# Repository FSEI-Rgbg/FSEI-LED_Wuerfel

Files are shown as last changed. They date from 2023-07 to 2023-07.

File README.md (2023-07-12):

# FSEI - LED Würfel - Lötübung

Dieses Projekt wurde als Lötübung ins Leben gerufen. Es handelt sich um eine kleine Platine mit 7 LEDs und einem Taster. Beim Drücken des Tasters wird eine Zahl zwischen 1 und 6 gewürfelt, wie bei einem echten Würfel auch.

## Wie sieht denn der Würfel eigentlich aus?
Bei einem solchen Projekt darf natürlich der FSEIgel nicht fehlen. Er hat selbstverständlich seinen ganz eigenen Platz auf der Platine bekommen.<p>
Wuerfel Version v1.0<p>
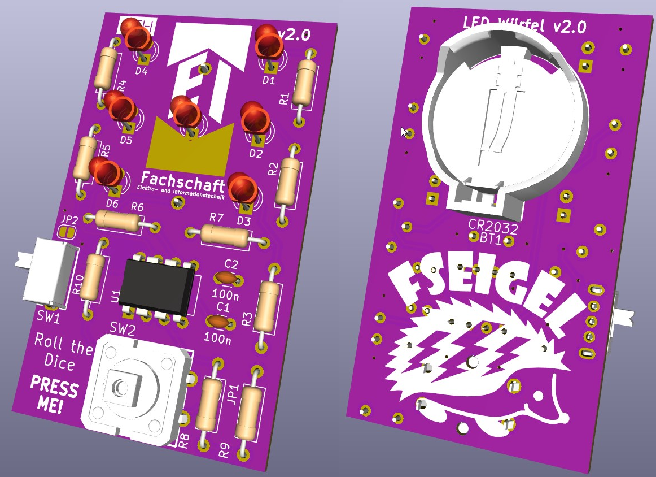
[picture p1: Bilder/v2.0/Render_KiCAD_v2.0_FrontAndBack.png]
Wuerfel Version v2.0
<p>
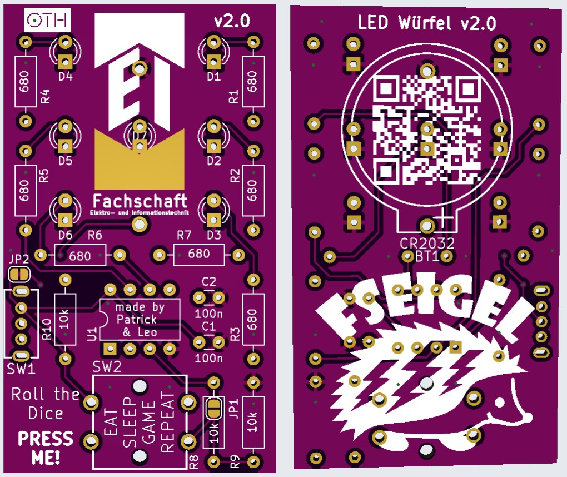
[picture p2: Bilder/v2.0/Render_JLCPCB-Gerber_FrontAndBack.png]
Wuerfel Version v2.0 Back
<p>
Eine [interaktive BOM](https://htmlpreview.github.io/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) zur einfachen Komponentenplatzierung gibt's natürlich auch.

## Projekt Status
Der Würfel ist voll funktionsfähig und als Lötübung in der Fachschaft Elektro- und Informationstechnik als Kit mit allen benötigten Komponenten sowie bereits installierter Software erhältlich.

Still ToDo:
- Version 2.0 ist (Stand 02.07.2023) noch UNTESTED!
- Dokumentation
- Bilder von KIT hinzufügen

## Zielgruppe / Dauer
<p> Diese Lötübung zielt auf alle Elektro- und Lötbegeisterten, oder die die es noch werden möchten, ab einem Alter von etwa 12-14 Jahren ab.
<p>Mit ein wenig handwerklichem Geschick kann nach etwa 30-45 Minuten losgewürfelt werden.

## Kit
**TODO** - _Bild folgt!_
<br>
<p>Der Würfel wird mit allen benötigten Bauteilen in einer kleinen Box herausgegeben. Enthalten ist alles, von der Platine, über die Batterie bis hin zu den LEDs.
<p>Wenn es für dich möglich ist, würden wir dich bitten, die Box nach erfolgreichem Zusammenbau wieder bei uns abzugeben.
<p>Danke für deine Mithilfe.

## Dokumentation
**TODO**
<br>
Eine Dokumentation wie alles funktioniert, zusammengebaut werden muss inkl. einer kurzen Erklärung für alles Weitere findest du [hier](/Doku/Dokumentation-FSEI-LED_Wuerfel_v2.0.pdf).<p>
Der interaktive Bestückungsplan ist [hier](https://htmlpreview.github.io/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) zu finden. Damit kannst du einfach der Reihe nach alle Komponenten einbauen und Stück für Stück abhaken, was du schon erledigt hast.

## Support
Bei Problemen, Fragen oder Anregungen bitte einfach bei der Fachschaft Elektro- und Informationstechnik (S060) melden.

## Software
**TODO**
<br>
Beim Drücken des Tasters wird ein Timer gestartet, außerdem startet eine Würfelanimation. Beim Loslassen des Tasters wird eine Zufallszahl gewürfelt, dargestellt und nach etwa 7 Sekunden wieder ausgeschalten. Durch die gedrückte Zeit des Tasters ergibt sich hierbei die Zufälligkeit. <p>
Weitere Details findest du in der [Dokumentation](#Dokumentation) oder im [Programmcode](/Software/Code/).

## Hardware
<p>Die Version 1.0 des Würfels wurde mit Hilfe von EasyEDA erstellt. Die Version 2.0 der Platine enthält einige Verbesserungen des ursprünglichen Designs und wurde in KiCAD realisiert.
<p>Im Mittelpunkt der Platine steht neben unserem FSEIgel natürlich ein kleiner Computer, ein sogenannter Mikroprozessor. Wir haben uns hierbei für den ATtiny13A von Atmel entschieden.

## Technische Daten / Stromverbrauch
- Stromaufnahme bei 3V: <p>
Modus  &  Stromaufnahme <p>
0,088 uA  @  Tiefschlafmodus <p>
0,9 mA  @  0 LEDs, CPU Idle <p>
1,808 mA  @  1 LED, CPU Idle <p>
10,8 mA  @  6 LEDs, CPU Idle

- Maße: 60 x 35 x ~10 mm

- Verwendungszweck: Würfel für Spieleabende

## Ich habe einen Bug gefunden oder eine Verbesserung
[Siehe Support](#Support)

## Wir sind ein Verein oder Gruppe von Studenten und wollen mehrere Bausätze kaufen
Es ist toll, dass du anderen Zeigen möchtest wie einfach Löten oder Elektrotechnik sein kann. Melde dich bei uns.

## Autoren
- Leo Scherer
- Patrick Lermer

## Inspired by
BlinkyParts
- https://github.com/Binary-Kitchen/SolderingTutorial
- https://binary-kitchen.github.io/SolderingTutorial/
- https://shop.blinkyparts.com/de/Bausaetze/

## Copyright and Authorship
[CC-BY-SA 4.0](https://creativecommons.org/licenses/by-sa/4.0/) - Fachschaft Elektro- und Informationstechnik der OTH Regensburg

[© FSEI OTH Regensburg](https://www.fsei-regensburg.de)

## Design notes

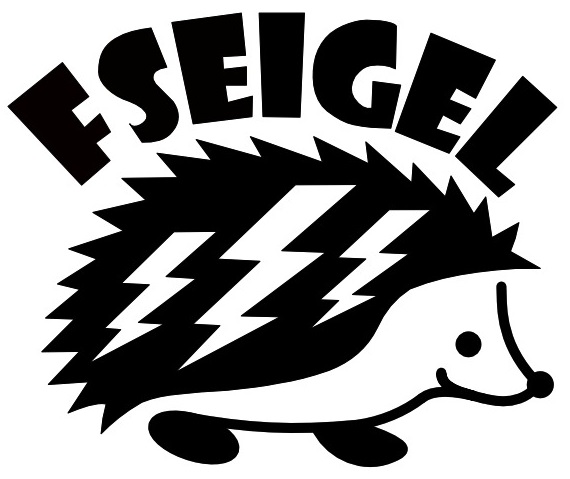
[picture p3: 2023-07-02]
Hardware - KiCAD/Pictures/FSEIgel.jpeg

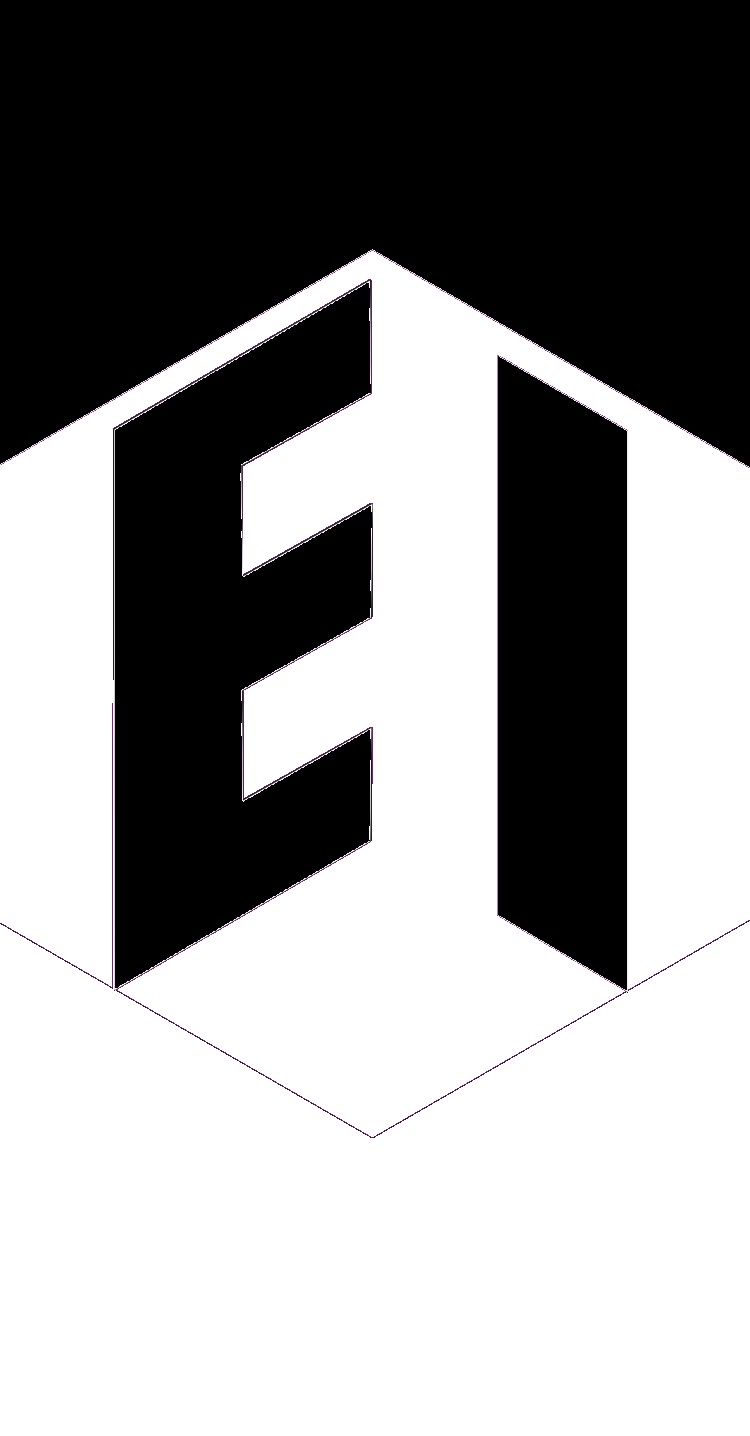
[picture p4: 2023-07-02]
Hardware - KiCAD/Pictures/FSEI_weiß.jpg

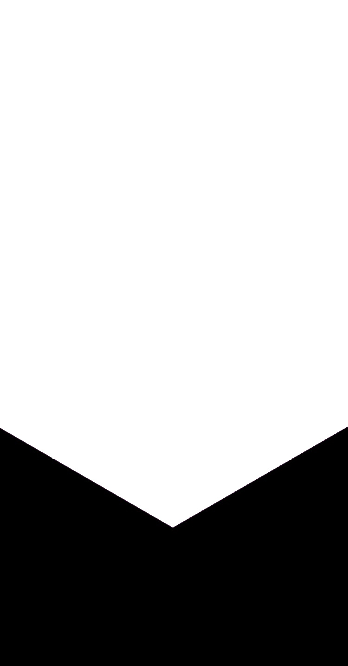
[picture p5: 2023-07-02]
Hardware - KiCAD/Pictures/FSEI_Copper.jpg

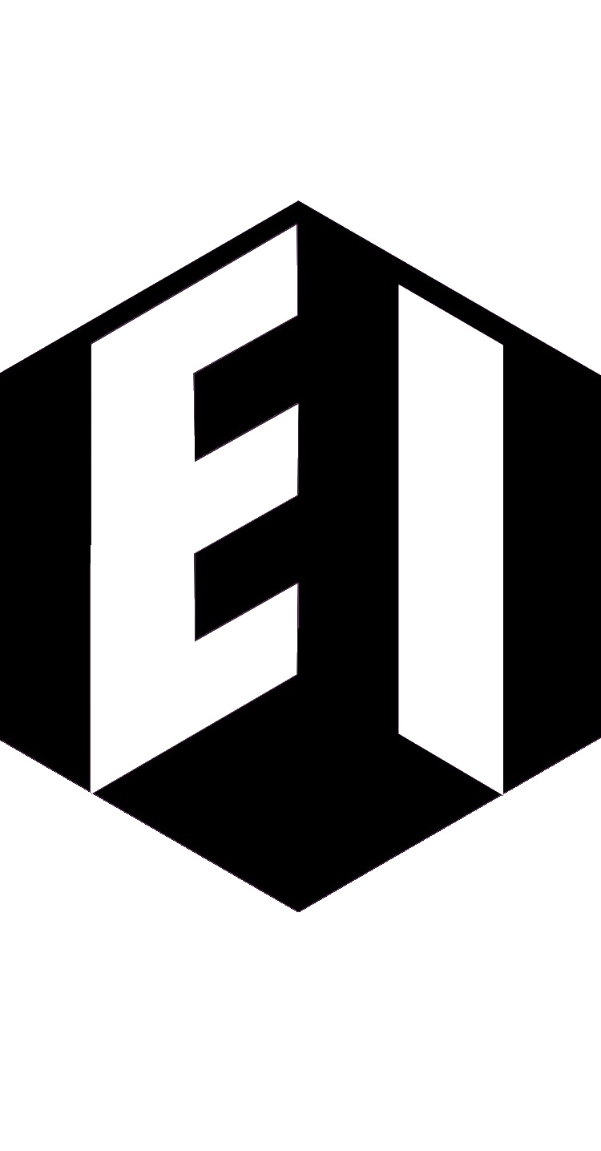
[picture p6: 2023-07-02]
Hardware - KiCAD/Pictures/FSEI_lila.jpg

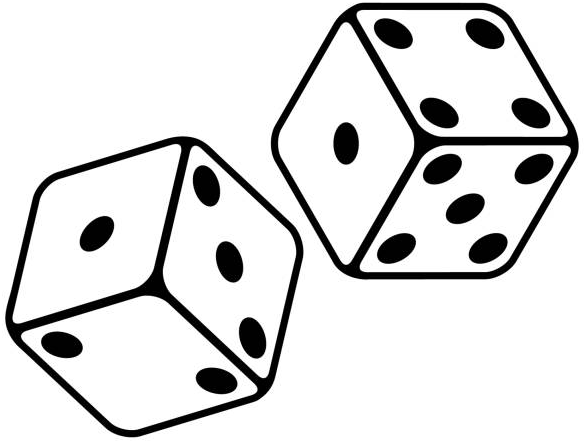
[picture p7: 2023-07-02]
Etiketten/Wuerfel.png

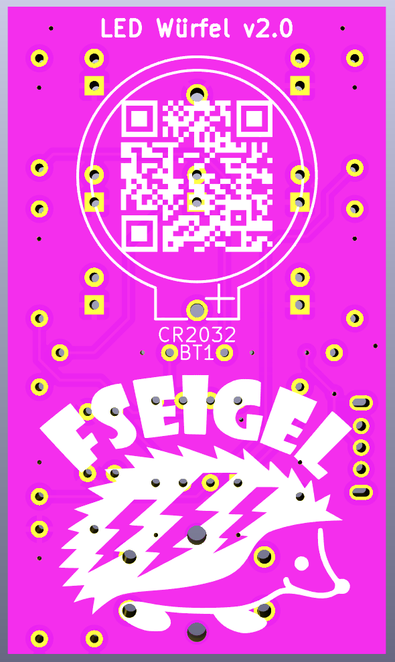
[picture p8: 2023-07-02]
Bilder/v2.0/Render_KiCAD_Back.png

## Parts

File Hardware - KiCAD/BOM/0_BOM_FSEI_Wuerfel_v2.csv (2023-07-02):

Source: | C:\Users\Patrick\OneDrive\Dokumente\FSEI\FSEI-LED_Wuerfel\Hardware - KiCAD\KiCAD-Project\FSEI_Wuerfel.kicad_sch
Date: | 6/22/2023 8:53:04 AM
Tool: | Eeschema 7.0.2
Generator: | C:\Program Files\KiCad\7.0\bin\scripting\plugins/bom_csv_grouped_by_value_with_fp.py
Component Count: | 25
Ref | Qnty | Value | Cmp name | Footprint | Description | Vendor | DNP
BT1 | 1 | CR2032 | Battery_Cell | C70376:BAT-TH_BS-2-1 | Single-cell battery
C1, C2 | 2 | 100n | C | Capacitor_THT:C_Disc_D3.0mm_W1.6mm_P2.50mm | Unpolarized capacitor
D1, D2, D3, D4, D5, D6, D7 | 7 | Red-TH-3mm | LED | LED_THT:LED_D3.0mm | Light emitting diode
JP1, JP2 | 2 | SolderJumper_2_Open | SolderJumper_2_Open | Jumper:SolderJumper-2_P1.3mm_Open_RoundedPad1.0x1.5mm | Solder Jumper, 2-pole, open
R1, R2, R3, R4, R5, R6, R7 | 7 | 680 | R | Resistor_THT:R_Axial_DIN0207_L6.3mm_D2.5mm_P10.16mm_Horizontal | Resistor
R8, R9, R10 | 3 | 10k | R | Resistor_THT:R_Axial_DIN0207_L6.3mm_D2.5mm_P10.16mm_Horizontal | Resistor
SW1 | 1 | SK12D07VG4 | SW_SPDT | C393937:SW-TH_SK12D07VG4 | Switch, single pole double throw
SW2 | 1 | Omron B3F-4055 | SW_MEC_5E | C84931:KEY-TH_4P-L12.0-W12.0-P5.00-LS13.4-EH | MEC 5E single pole normally-open tactile switch
U1 | 1 | ATtiny13A-P | ATtiny13A-P | Package_DIP:DIP-8_W7.62mm | 20MHz, 1kB Flash, 64B SRAM, 64B EEPROM, debugWIRE, DIP-8

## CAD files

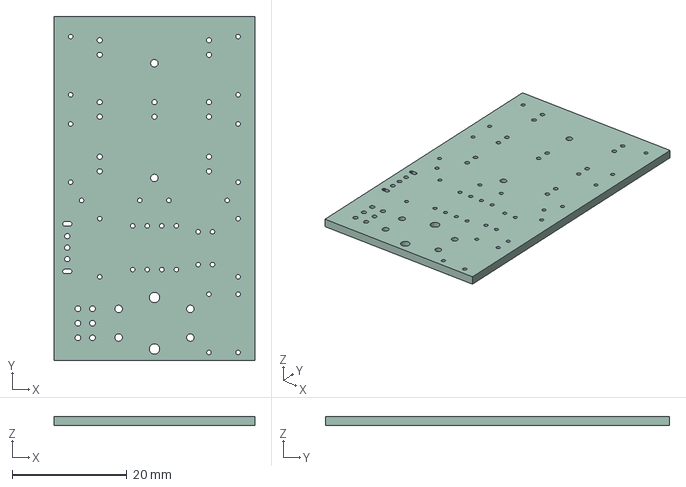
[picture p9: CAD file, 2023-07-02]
Hardware - KiCAD/KiCAD-Project/FSEI_Wuerfel.step
35.0 x 60.0 x 1.60 mm

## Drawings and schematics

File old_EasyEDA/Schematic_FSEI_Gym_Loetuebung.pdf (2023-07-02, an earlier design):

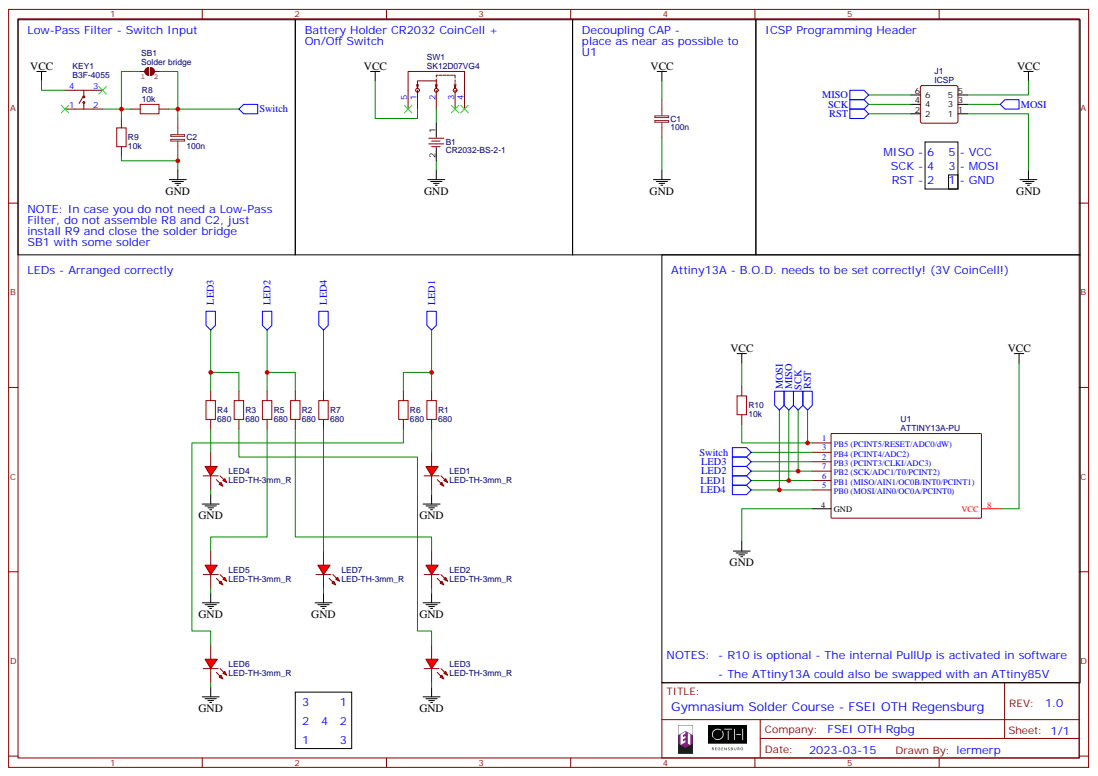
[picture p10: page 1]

Decoupling CAP -
place as near as possible to

NOTE: In case you do not need a Low-Pass
Filter, do not assemble R8 and C2, just
install R9 and close the solder bridge
SB1 with some solder

- R10 is optional - The internal PullUp is activated in software
- The ATtiny13A could also be swapped with an ATtiny85V

Company: FSEI OTH Rgbg

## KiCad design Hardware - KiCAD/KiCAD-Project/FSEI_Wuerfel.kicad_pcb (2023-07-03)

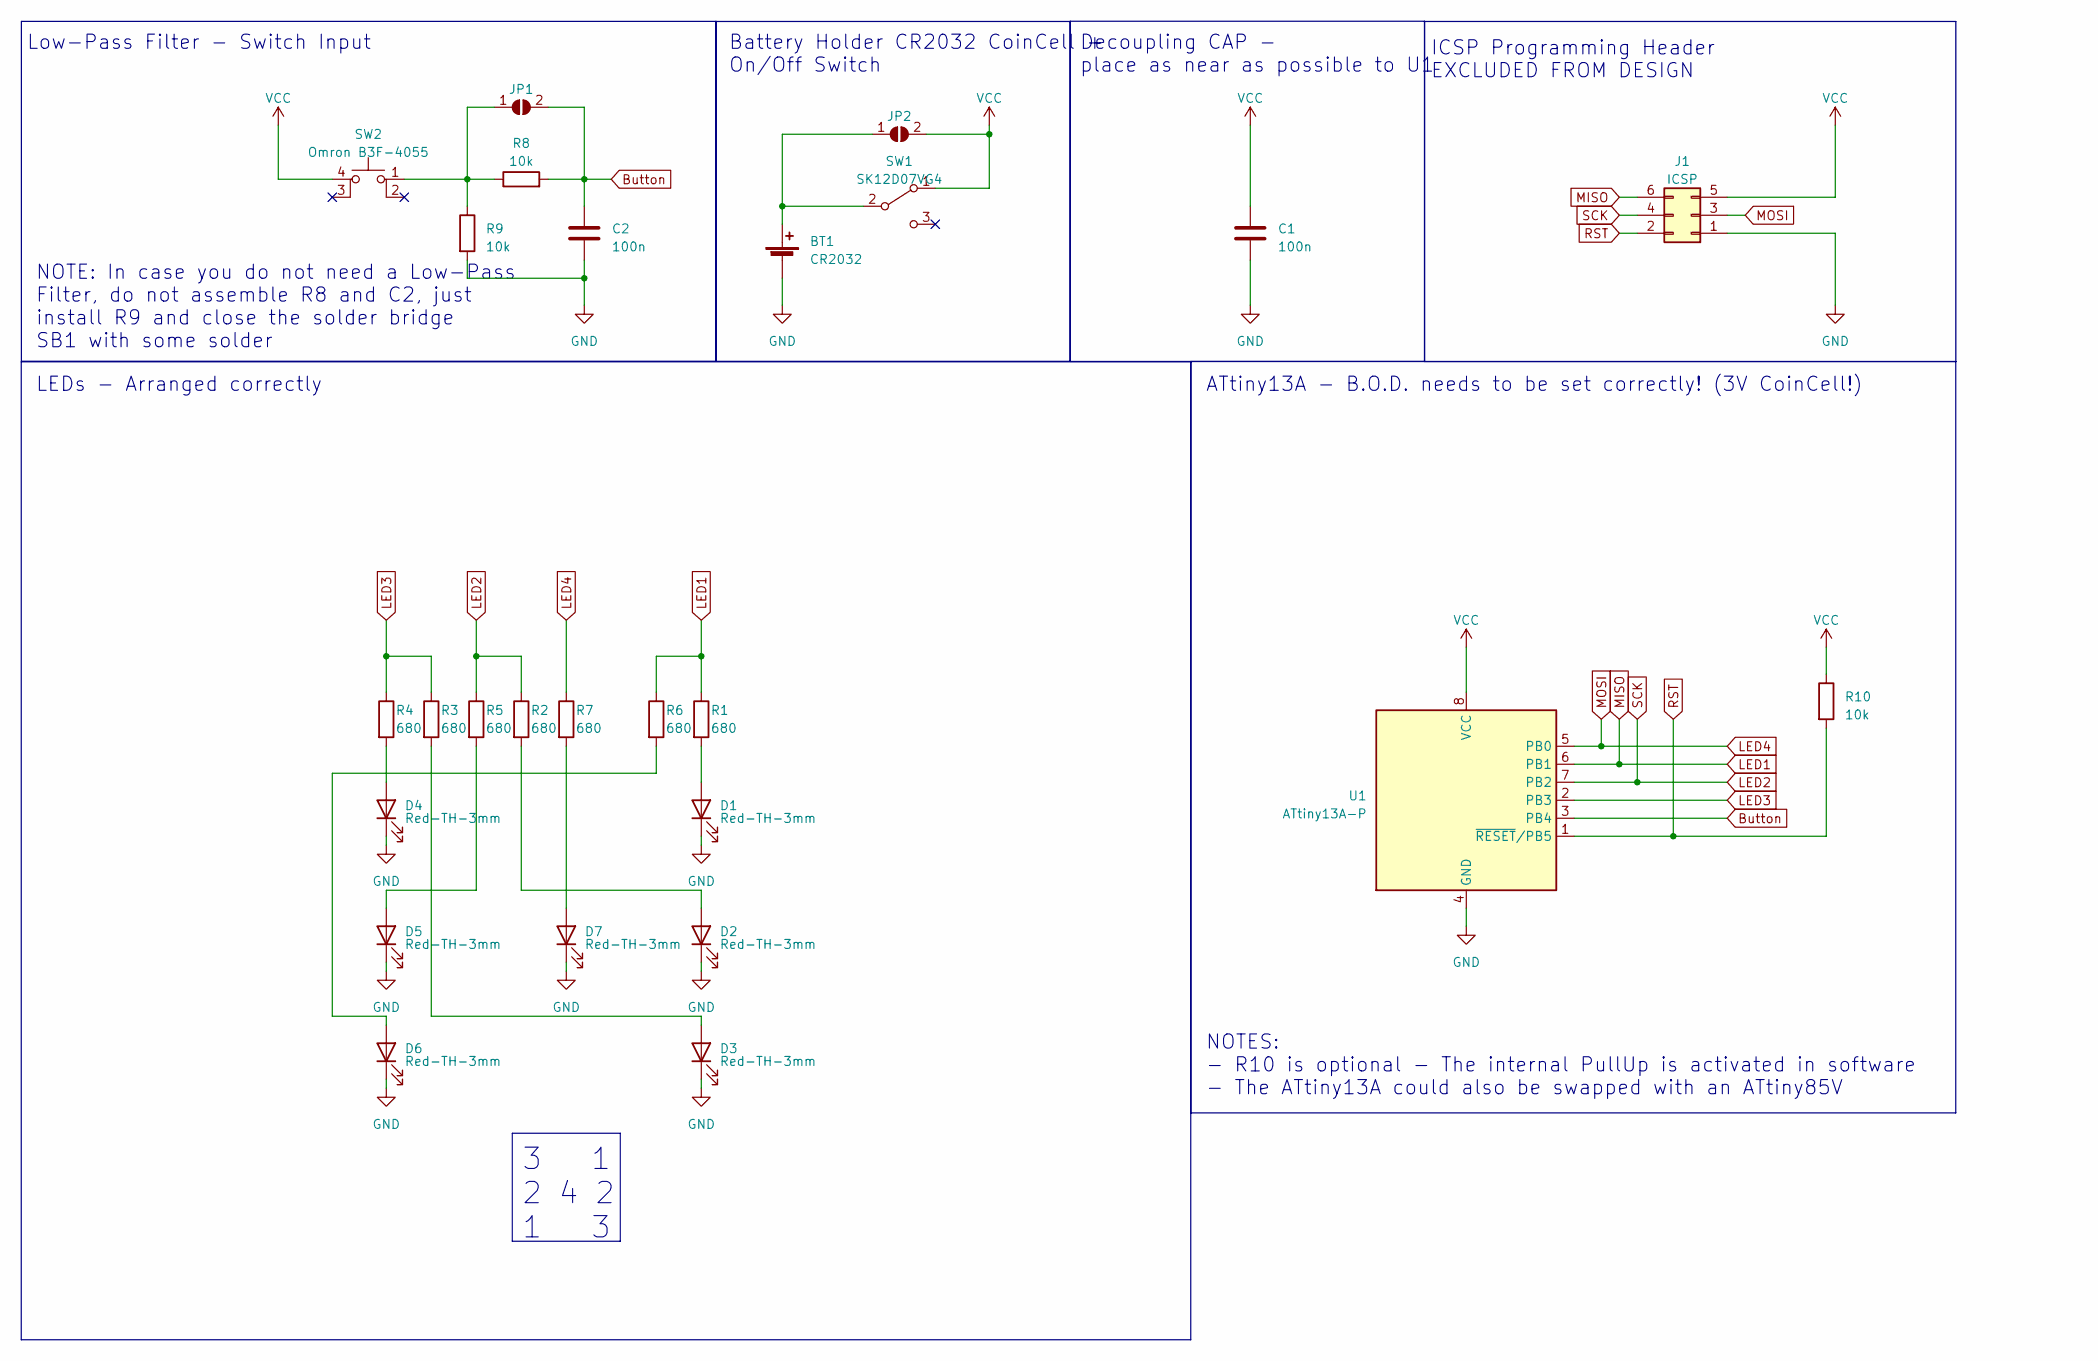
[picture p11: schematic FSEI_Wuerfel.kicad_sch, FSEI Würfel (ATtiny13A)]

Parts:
BT1: CR2032; BAT-TH_BS-2-1
C1, C2: 100n; C_Disc_D3.0mm_W1.6mm_P2.50mm
D1, D2, D3, D4, D5, D6, D7: Red-TH-3mm; LED_D3.0mm
J1: ICSP; PinSocket_2x03_P2.54mm_Vertical
JP1, JP2: SolderJumper_2_Open; SolderJumper-2_P1.3mm_Open_RoundedPad1.0x1.5mm
R1, R2, R3, R4, R5, R6, R7: 680; R_Axial_DIN0207_L6.3mm_D2.5mm_P10.16mm_Horizontal
R8, R9, R10: 10k; R_Axial_DIN0207_L6.3mm_D2.5mm_P10.16mm_Horizontal
SW1: SK12D07VG4; SW-TH_SK12D07VG4
SW2: Omron B3F-4055; KEY-TH_4P-L12.0-W12.0-P5.00-LS13.4-EH
U1: ATtiny13A-P; DIP-8_W7.62mm

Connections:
Button: C2.1, JP1.2 (B), R8.2, U1.3 (PB4)
GND: BT1.2 (-), C1.2, C2.2, D1.1 (K), D2.1 (K), D3.1 (K), D4.1 (K), D5.1 (K), D6.1 (K), D7.1 (K), J1.1, R9.2, U1.4 (GND)
LED1: J1.6, R1.1, R6.1, U1.6 (PB1)
LED2: J1.4, R2.1, R5.1, U1.7 (PB2)
LED3: R3.1, R4.1, U1.2 (PB3)
LED4: J1.3, R7.1, U1.5 (PB0)
unnamed: BT1.1 (+), JP2.1 (A), SW1.2 (B)
unnamed: D1.2 (A), R1.2
unnamed: D2.2 (A), R2.2
unnamed: D3.2 (A), R3.2
unnamed: D4.2 (A), R4.2
unnamed: D5.2 (A), R5.2
unnamed: D6.2 (A), R6.2
unnamed: D7.2 (A), R7.2
unnamed: JP1.1 (A), R8.1, R9.1, SW2.1
RST: J1.2, R10.2, U1.1 (~RESET/PB5)
VCC: C1.1, J1.5, JP2.2 (B), R10.1, SW1.1 (A), SW2.4 (A), U1.8 (VCC)

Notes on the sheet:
3 1 2 4 2 1 3
ICSP Programming Header EXCLUDED FROM DESIGN
NOTE: In case you do not need a Low-Pass Filter, do not assemble R8 and C2, just install R9 and close the solder bridge SB1 with some solder
Decoupling CAP - place as near as possible to U1
Low-Pass Filter - Switch Input
NOTES: - R10 is optional - The internal PullUp is activated in software - The ATtiny13A could also be swapped with an ATtiny85V
ATtiny13A - B.O.D. needs to be set correctly! (3V CoinCell!)
Battery Holder CR2032 CoinCell + On/Off Switch
LEDs - Arranged correctly

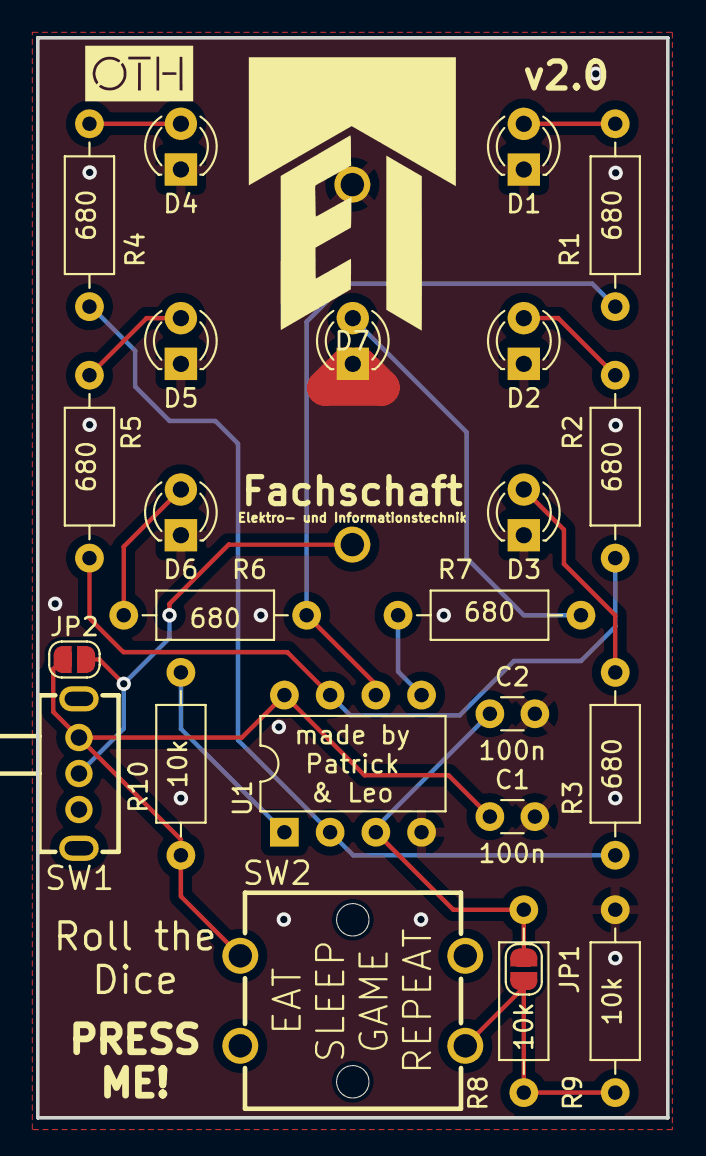
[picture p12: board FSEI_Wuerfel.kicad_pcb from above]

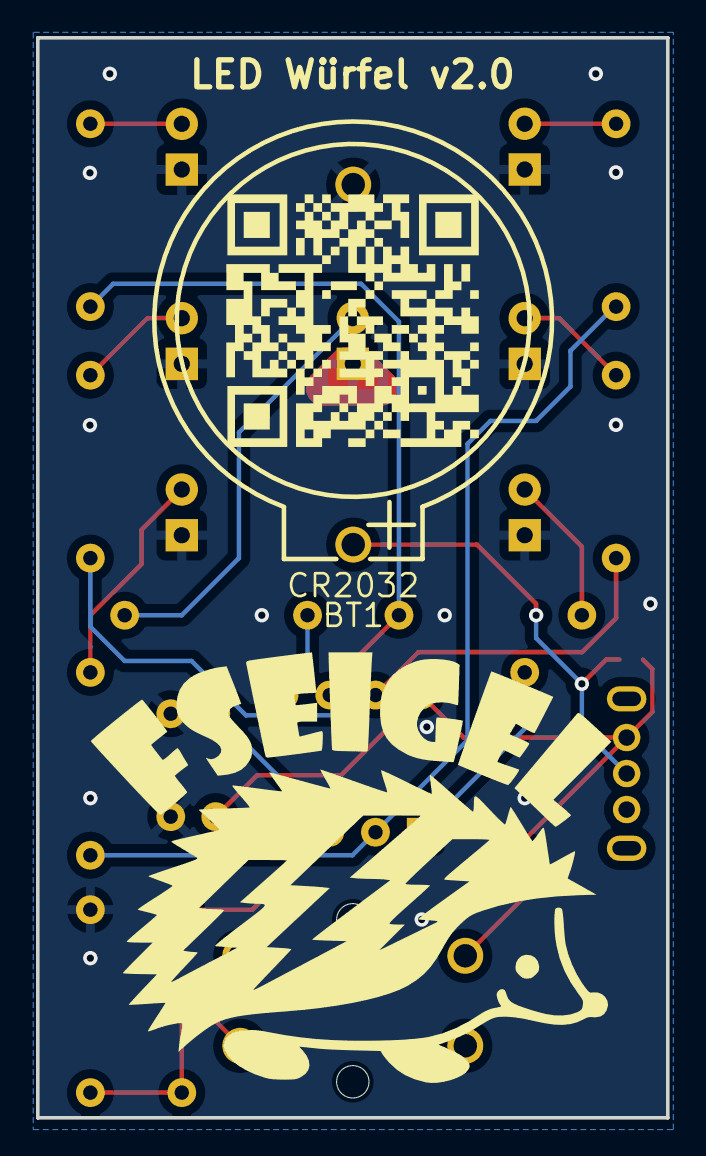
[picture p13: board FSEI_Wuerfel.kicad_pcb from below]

Board: 2 copper layers, 35.0 x 60.0 mm, 30 parts (3 on the bottom side), 17 nets.

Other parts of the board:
G01, G02, G011, G012, G100: LOGO

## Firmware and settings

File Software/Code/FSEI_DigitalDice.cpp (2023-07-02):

/*
Fachschaft Elektro- & Informationstechnik, OTH Regensburg, ©2023

Digitaler Würfel - Lötübung
ATtiny13A oder ATtiny85V

Inputs:    
    Taster mit PullDown und LowPassFilter an PB4 (Pin 3) - Interrupt PCINT4

Outputs:   
    LED Gruppen:
        LED1 = PB1 (Pin 6)
        LED2 = PB2 (Pin 7)
        LED3 = PB3 (Pin 2)
        LED4 = PB0 (Pin 5)
    ┌───┐   ┌───┐
    │ 3 │   │ 1 │
    ├───┼───┼───┤
    │ 2 │ 4 │ 2 │
    ├───┼───┼───┤
    │ 1 │   │ 3 │
    └───┘   └───┘

Funktionsprinzip:
    uC geht direkt in Tiefschlafmodus um Strom zu sparen.
    Sobald der Taster gedrückt wird, aktiviert sich der Timer (der mit 9,6MHz zählt), 
    und zählt endlos nach oben und läuft über. Die CPU ist dabei Idle.
    Sobald der Taster losgelassen wird, wird per XOR und Modulo aus dem Wert des Timers die anzuzeigende Zahl bestimmt.
    Dann wird der Interrupt des Timers aktiviert, welcher den TIMER_COUNTER solange hochzählt, 
    bis etwa 7s vergangen sind. Dann wird alles deaktiviert und wieder in den Tiefschlafmodus versetzt.

Stromaufnahme bei 3V:
    Tiefschlafmodus:    0,088 uA
    0 LEDs, CPU Idle:     0,9 mA
    1 LED, CPU Idle:    1,808 mA
    6 LEDs, CPU Idle:    10,8 mA
*/

// Einbinden aller benötigten Bibliotheken (Zusatzfunktionen)
#include <avr/io.h>
#include <avr/interrupt.h>
#include <avr/sleep.h>

// Timer Modus für das Warten auf Abschaltung, dadurch hat er einen hohen Prescaler und wenig Interrupts.
#define TMODE_IDLE 0
// Timer Modus für das Ermitteln einer Zufallszahl, dafür wird die höchste Auflösung und kein Prescaler benötigt.
#define TMODE_TRNG 1


// Zusätzlicher Zähler, um den Timer auf 24-Bit zu erweitern.
volatile unsigned short TIMER_COUNTER = 0;
// Timer Modus Variable, die den derzeitigen Zustand speichert.
volatile unsigned char TIMER_USAGE_MODE = 0;
// Zähler für das Durchlaufen aller Würfelzustände
volatile unsigned char DICE_ANIM_COUNTER = 0;
// Speicher für den vorherigen Würfel-Wurf.
volatile unsigned char PREV_DICE_ROLL = 0;


// Ausgabe der gewürfelten Augenzahl auf LEDs. Rest von PORTB bleibt unverändert.
void DisplayAugenzahl(unsigned char Zahl)     
{
    // Alle LEDs deaktivieren
    PORTB &= ~((1 << PORTB3) | (1 << PORTB2) | (1 << PORTB1) | (1 << PORTB0));

    switch (Zahl)
    {
        case 1: //LED4
            PORTB |= (1 << PORTB0);
        break;

        case 2: // LED1
            PORTB |= (1 << PORTB1);
            break;

        case 3: // LED1 & LED4
            PORTB |= ((1 << PORTB1) | (1 << PORTB0));
            break;

        case 4: // LED1 & LED3
            PORTB |= ((1 << PORTB1) | (1 << PORTB3));
            break;

        case 5: // LED1 & LED3 & LED4
            PORTB |= ((1 << PORTB1) | (1 << PORTB3) | (1 << PORTB0));
            break;

        case 6: // LED1 & LED2 & LED3
            PORTB |= ((1 << PORTB1) | (1 << PORTB2) | (1 << PORTB3));
            break;

        default: 
            break;
    }
}


// Timer im jeweiligen Modus aktivieren und mit einem festgelegten Wert starten.
void activate_timer(unsigned char timer_mode, unsigned char timer_value)
{
    TCCR0B = 0x00;                              // Timer stoppen falls er schon läuft.
    TIMER_USAGE_MODE = timer_mode;              // Timer Modus für Interrupt Routine speichern.
    TIMER_COUNTER = 0;                          // Zusätzlichen Timer Counter zurücksetzen.
    TCNT0 = timer_value;                        // Timer Wert setzen.

    TIMSK0 = (1 << TOIE0);                      // Timer-Interrupt anschalten.

    switch (timer_mode)
    {
        case TMODE_IDLE:
            TCCR0B = ((1 << CS02) | (1 << CS00));// Timer anschalten mit Prescaler 1024.
            break;
        case TMODE_TRNG:
            TCCR0B = (1 << CS00);               // Timer ohne Prescaler anschalten.
            break;
        default:                                // etwas ist falsch, timer nicht starten.
            break;
    }
}


// Interrupt Service Routine (ISR) für Flankenwechsel des Tasters. Pin 4 ist High wenn dieser gedrückt wird.
ISR(PCINT0_vect)
{
    if (PINB & (1 << PINB4))                    // Eingang PIN4 abfragen: Taster gedrückt -> Steigende Flanke
    {
        DICE_ANIM_COUNTER = 0;                  // Animations-Zähler für Zwischenanimation zurücksetzen

        activate_timer(TMODE_TRNG, PREV_DICE_ROLL); // Aktiviere den Timer im Zufallszahlen-Modus

        set_sleep_mode(SLEEP_MODE_IDLE);        // Sleep Mode zu nur Idle ändern, damit die Oszillatoren an bleiben und der Timer zählen kann.
    }
    else                                        // Taster nicht gedrückt -> Fallende Flanke
    {
        PREV_DICE_ROLL ^= TCNT0;                // Alten Timer Wert mit neuem Wert XORen für eine bessere Gleichverteilung der Werte und speichern.

        DisplayAugenzahl((PREV_DICE_ROLL % 6) + 1);  // Zufallsgenerierte Zahl aus Timer Wert berechnen und anzeigen.

        activate_timer(TMODE_IDLE, 0);          // Aktiviere den Timer für die Idle-Abschaltung
    }
}

// Interrupt Service Routine (ISR) für den Overflow des Timers. Wird alle 1 / 9,6 MHz * Prescaler * 255 Sekunden aufgerufen.
// Der Prescaler ist 1 im TMODE_TRNG und 1024 im TMODE_IDLE.
ISR(TIM0_OVF_vect)                              
{                                               

    TIMER_COUNTER += 1;                         // TIMER_COUNTER hochzählen. Dient als Erweiterung für den 8-Bit Counter.

    if (TIMER_USAGE_MODE == TMODE_IDLE)         // Wenn der Timer für die Idle-Abschaltung nach zu langer Zeit verwendet wird:
    {
        if (TIMER_COUNTER >= 255)               // Überprüfe ob etwa 7 Sekunden vergangen sind. Falls ja, System für den Tiefschlaf vorbereiten:
        {            
            TCCR0B = 0x00;                      // Timer stoppen.
            TIMSK0 = 0x00;                      // Timer-Interrupt ausschalten.
            DisplayAugenzahl(0);                // Alle LEDs ausschalten.
            set_sleep_mode(SLEEP_MODE_PWR_DOWN);// Sleep Mode zu kompletten Tiefschalf ändern. nach der ISR wird durch die while Schleife in main der Schlaf gestartet.
        }
    }
    else if (TIMER_USAGE_MODE == TMODE_TRNG)    // Wenn der Timer für die Zufallszahlengenerierung verwendet wird:
    {
        if (TIMER_COUNTER >= 6300)              // Überprüfe ob etwa 1/6 einer Sekunde vergangen ist.
        {
            DICE_ANIM_COUNTER += 1;             // Animations-Counter zum Anzeigen eines "hochzählenden" Würfels zurücksetzen.
            DisplayAugenzahl(DICE_ANIM_COUNTER % 6 + 1);    // Zahl anzeigen.
            TIMER_COUNTER = 0;                  // Timer zurücksetzen.
        }
    }
}


int main() 
{ 
    // Interrupts deaktivieren & initialisieren
    cli();   

    // Definieren der PB0-PB3 Outputs, PB4 Input, PB5 Input
    DDRB = ((1 << DDB3) | (1 << DDB2) | (1 << DDB1) | (1 << DDB0));

    // Vorrübergehend: Pull-Up auf Reset Pin aktivieren. Eigentlich ist PB5 durch R10 auf High gezogen.
    PORTB |= (1 << PORTB5);

    // Timer auf Normal Mode stellen (ist normalerweise default)
    TCCR0A = 0x00;

    // Setzen aller Register für Pin Change Interrupt PCINT4
    PCMSK = (1 << PCINT4);  // Pin Change Interrupt für Pin 4 demaskieren
    GIMSK |= (1 << PCIE);   // Pin Change Interrupt aktivieren
    
    // ADC Modul deaktiveren um Strom zu sparen.
    PRR = (1 << PRADC);

    // Tiefschalfmodus als Schlafmodus setzen. 
    set_sleep_mode(SLEEP_MODE_PWR_DOWN); 
    
    // Interrupts aktivieren
    sei();          

    // Endlos schlafen gehen sobald er wieder aufwacht.
    do
    {
        sleep_mode();
    } while(1);
}
